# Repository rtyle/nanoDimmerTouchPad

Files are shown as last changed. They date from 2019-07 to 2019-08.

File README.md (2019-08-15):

This contains the design of a printed circuit board that can be powered by an Aeotec Nano Dimmer. It provides a touch pad that acts as an external momentary switch to the Nano Dimmer for controlling its load.

The size of the circuit board is suited for replacing the smarts in a Legrand Adorne touch switch.

The CAMOutputs can be zipped up and sent to a board fabrication shop.

Tuning ...

R1 (4k7Ω) was chosen to roughly match the LED intensity of an original Legrand Adorne touch switch.

According the the AT42QT1010 sensor datasheet (http://ww1.microchip.com/downloads/en/devicedoc/40001946a.pdf), touch sensitivity can be increased by increasing Cs, usually from 2–50nF. This (C2, 10nF) was chosen to match that on a SparkFun Capacitive Touch Breakout board (https://www.sparkfun.com/products/12041). On the bench, however, this seemed too sensitive and  was changed to 6.6nF (3 2.2nF stacked).

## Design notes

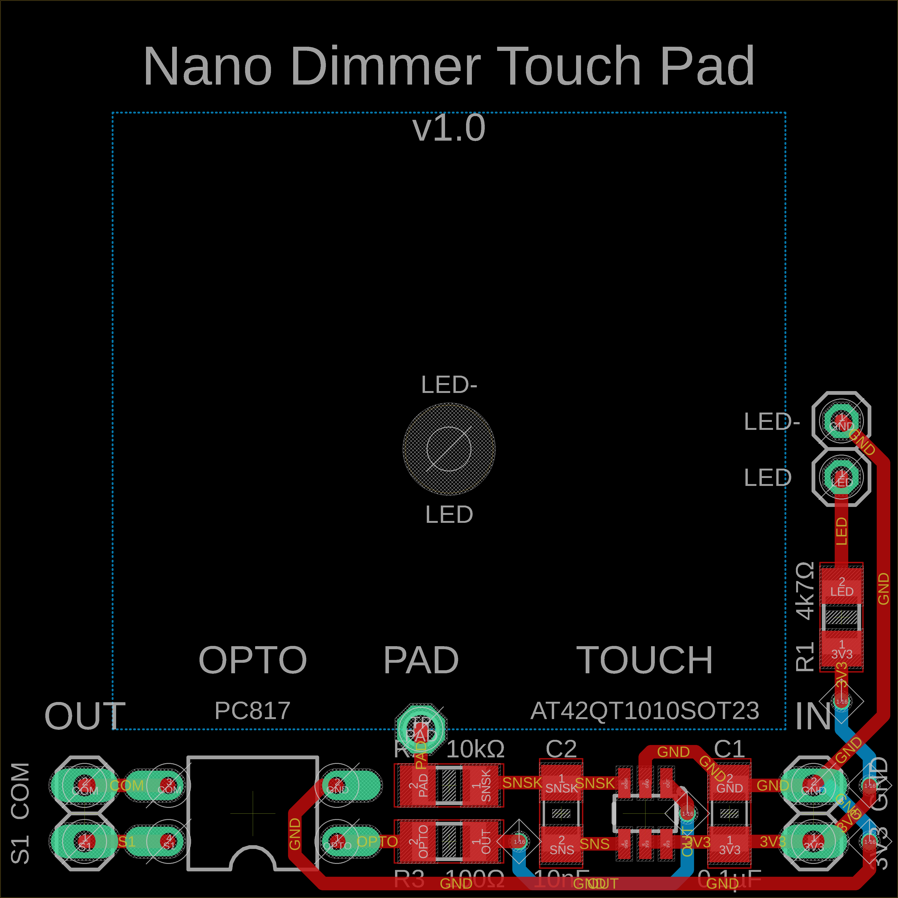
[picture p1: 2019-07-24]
eagle/nanoDimmerTouchPad.brd.png

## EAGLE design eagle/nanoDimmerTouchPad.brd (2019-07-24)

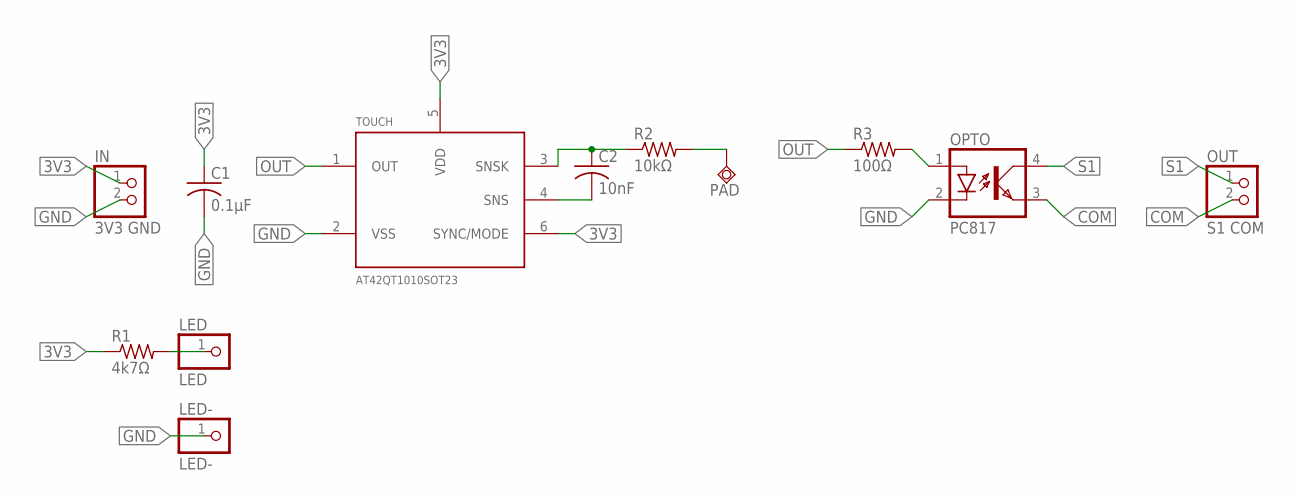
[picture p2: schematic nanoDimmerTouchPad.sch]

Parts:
C1: 0.1µF; C1206
C2: 10nF; C1206
IN: 3V3 GND; 1X02
LED: LED; 1X01
LED-: LED-; 1X01
OPTO: PC817; DIL04
OUT: S1 COM; 1X02
PAD: TPSQPAD1-13; P1-13
R1: 4k7Ω; R1206
R2: 10kΩ; R1206
R3: 100Ω; R1206
TOUCH: AT42QT1010SOT23; SOT23-6

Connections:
3V3: C1.1, IN.1, R1.1, TOUCH.5 (VDD), TOUCH.6 (SYNC/MODE)
COM: OPTO.3 (EMIT), OUT.2
GND: C1.2, IN.2, LED-.1, OPTO.2 (C), TOUCH.2 (VSS)
LED: LED.1, R1.2
OPTO: OPTO.1 (A), R3.2
OUT: R3.1, TOUCH.1 (OUT)
PAD: PAD.TP, R2.2
S1: OPTO.4 (COL), OUT.1
SNS: C2.2, TOUCH.4 (SNS)
SNSK: C2.1, R2.1, TOUCH.3 (SNSK)

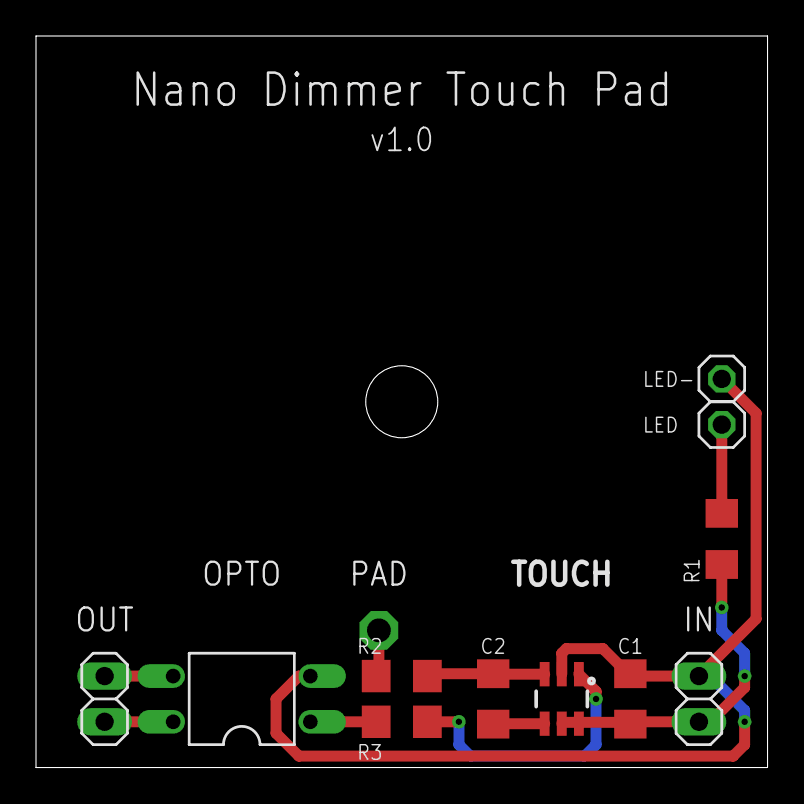
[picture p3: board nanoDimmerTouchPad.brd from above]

Board: 2 copper layers, 40.6 x 40.6 mm, 12 parts (0 on the bottom side), 10 nets.

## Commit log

2019-07-19 remove executable bit
    [nanoDimmerTouchPad.brd, nanoDimmerTouchPad.sch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]
2019-07-19 Update README.md
    add fabrication and assembly instructions
2019-07-19 Update README.md
    momentary switch
2019-07-19 change indicator LED resistor from 100 to 4700 ohm to match Legrand Adorne brightness
    [nanoDimmerTouchPad.brd, nanoDimmerTouchPad.sch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]
2019-07-24 v1.0: paranoid isolation of sense circuits, no ground planes, SMD resistors and capacitors
    [nanoDimmerTouchPad.brd, nanoDimmerTouchPad.sch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]
2019-07-24 chmod a-x
    [nanoDimmerTouchPad.brd, nanoDimmerTouchPad.sch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]
2019-07-24 move via totally on board
    [nanoDimmerTouchPad.brd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]

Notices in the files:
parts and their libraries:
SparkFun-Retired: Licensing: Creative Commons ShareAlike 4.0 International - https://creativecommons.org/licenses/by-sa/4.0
